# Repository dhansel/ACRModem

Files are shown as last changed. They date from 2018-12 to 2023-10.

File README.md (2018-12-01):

# ACRModem

The 88-ACR Audio Cassette Interface provided a means for Altair 8800 users
to save and load data on audio cassettes.

The 88-ACR consisted of two parts: A serial interface (identical to 88-SIO)
and a modulator/demodulator to convert the serial bit stream to an audio
signal (and vice versa).

This project represents the modulator/demodulator part, to be used with the
[Altair 8800 Simulator](https://www.hackster.io/david-hansel/arduino-altair-8800-simulator-3594a6). The function is fairly simple:
1) Connect the serial input of the modulator/demodulator board
to a serial interface of the Altair Simulator.
2) Connect the audio input of the board to the headphone output of an audio 
cassette recorder and the audio output of the board to the microphone
input of the cassette recorder.
3) Configure the serial interface on the Simulator for 300 baud.
4) In the Simulator configuration menu, map the 88-ACR card to the
serial interface to which the modulator/demodulator is connected.

Any data sent to the 88-ACR card by software running in the Simulator
should now appear on the microphone input of the cassette recorder and
data played back on the recorder should be visible on the 88-ACR card.

You will likely need to adjust recording level and volume on the cassette
recorder to find levels that work well.

## Hardware

The modulator/demodulator hardware is based on an ATMega 328p MCU
and a LM358 OpAmp. The ACRModem.fzz Fritzing file contains the schematic
as well as a working stripboard layout.

## Software

The ACRModem.ino file can be uploaded to the ATMega using the Arduino
development GUI. There are plenty of descriptions on how to upload
Arduino sketches to a stand-alone ATMega available on the internet.
Search for "Breadboard Arduino" or use [this link](http://www.buildcircuit.com/make-arduino-on-breadboard-using-ftdi-breakout-board).

## Acknowledgements

This project is loosely based on Mike Douglas' implementation
of an [Audio Cassette Interface](http://altairclone.com/cassette.htm) 
for the [Altair 8800 clone](http://altairclone.com/).

Thanks to Mike for tracking down the original 88-ACR documentation,
collecting supporting files and making the plans for his interface [available to the public](http://altairclone.com/downloads/cassette_interface/Hardware).

Although the implementation is different, the function of the two should
be almost identical. Instead of building this project here, purchasing
one of Mike's interfaces and hooking it up to the Altair Simulator
should work just the same.

For much more information on how to use the cassette interface on the
Altair 8800, see Mike's [documentation](http://altairclone.com/downloads/manuals/Cassette%20Interface%20Manual.pdf) 
for his cassette interface. Obviously his documentation was written for the Altair Clone
so following the instructions will be slightly different when used with an Altair Simulator.

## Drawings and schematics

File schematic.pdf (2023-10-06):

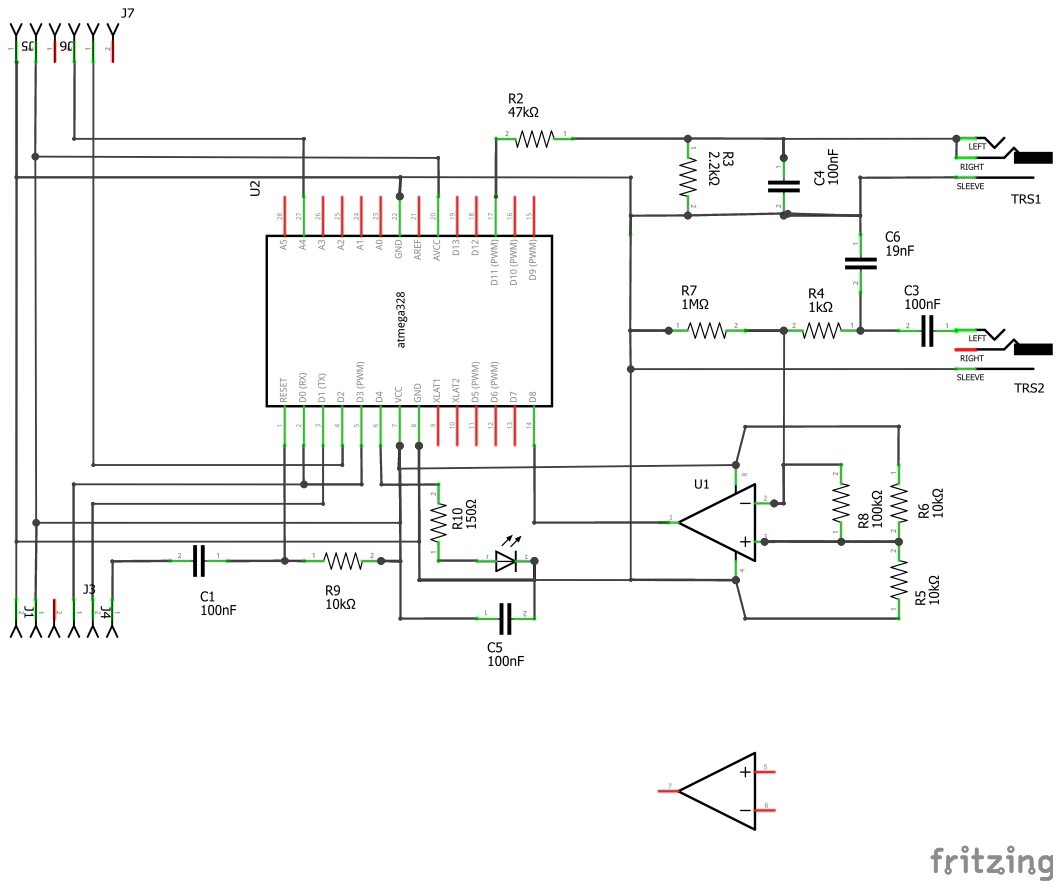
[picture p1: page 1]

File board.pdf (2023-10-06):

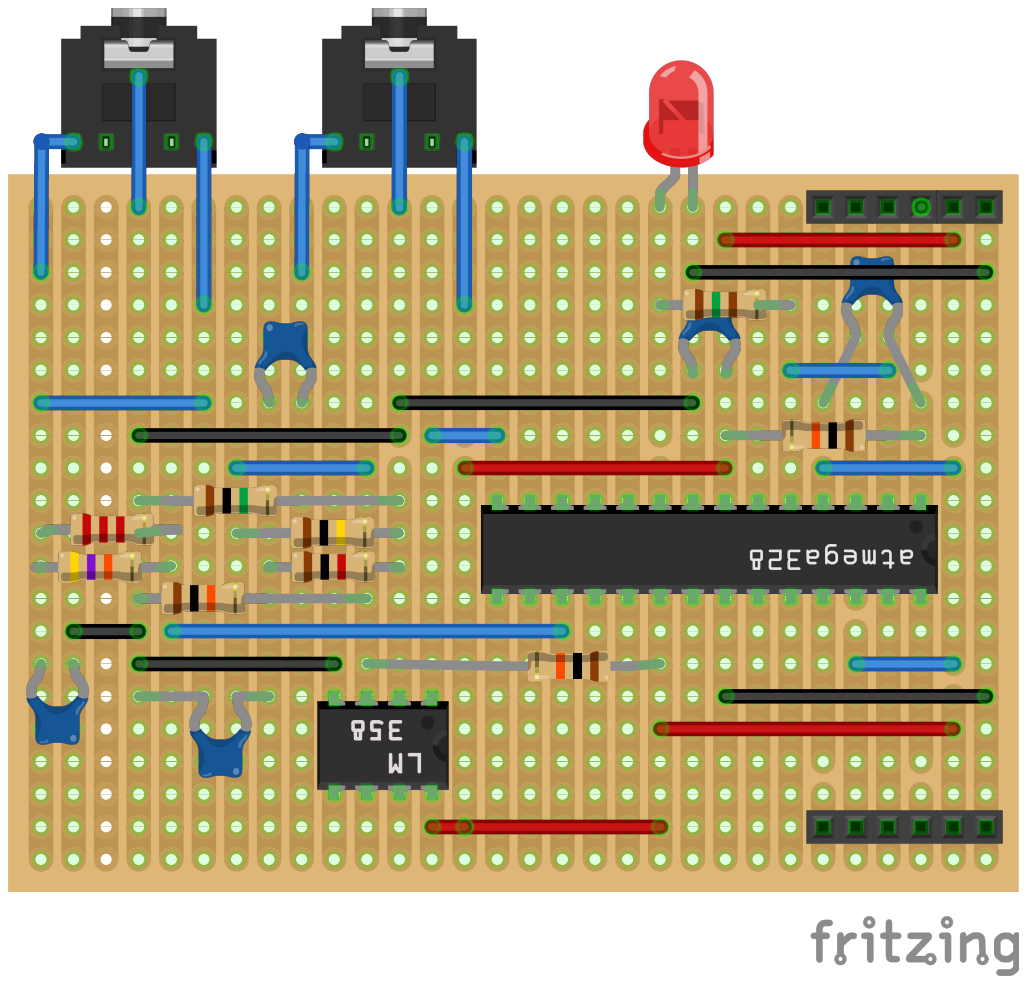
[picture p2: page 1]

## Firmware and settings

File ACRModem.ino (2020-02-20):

// -----------------------------------------------------------------------------
// Modulator/Demodulator for 88-ACR Altair Audio Cassette Interface (300 baud)
// Copyright (C) 2018 David Hansel
//
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
#define PIN_SERIAL_IN   2  // must be 2 or 3 (uses interrupt pin INT0 or INT1)
#define PIN_SERIAL_OUT A4  // can be any pin
#define PIN_AUDIO_IN    8  // must be  8 (hardwired ICP1 for timer1)
#define PIN_AUDIO_OUT  11  // must be 11 (hardwired OC2A for timer2)
#define PIN_LED         4  // can be any pin

// timing values for audio output:
// 8Mz main clock with /32 pre-scaler, the output toggles on 
// timer compare match so the timer must count up twice for a full wave:
#define OCRA_1850HZ  67 // 8000000/32/2/1850 = 67.57 = 541 microseconds
#define OCRA_2400HZ  52 // 8000000/32/2/2400 = 52.08 = 417 microseconds

// timing values for audio input
#define PERIOD_MAX_US 2000  // 1000Hz = 2000 microseconds
#define PERIOD_MID_US  471  // 2125Hz =  471 microseconds
#define PERIOD_MIN_US  333  // 3000Hz =  333 microseconds

// number of good audio pulses in a row required before entering "send" mode
#define NUM_GOOD_PULSES 100

// number of bad audio pulses in a row required before exiting "send" mode
// at 300 baud and audio frequencies of 1850 and 2400Hz, one bit is made up
// of 6-8 pulses. So if we just keep outputting the previous bit value then
// one or two bad pulses may not result in a receive error.
#define NUM_BAD_PULSES  3

// are we in "send" mode?
volatile bool send_data = false;

// timer value for current audio output frequency
volatile byte audio_out_timer_value = OCRA_2400HZ;


void got_pulse(bool good)
{
 static volatile byte good_pulses = 0, bad_pulses = 0;

 if( good )
  {
    bad_pulses = 0;
    if( good_pulses<NUM_GOOD_PULSES ) 
      {
        good_pulses++;
        if( good_pulses==NUM_GOOD_PULSES ) 
          { 
            digitalWrite(PIN_LED, HIGH); 
            send_data = true; 
          }
        else
          {
            // enable timer 1 overflow interrupt (checks for too-long pulse)
            TIFR1  |= bit(OCF1A);
            TIMSK1 |= bit(OCIE1A);
          }
      }
  }
 else if( bad_pulses<NUM_BAD_PULSES )
   {
     bad_pulses++;
     if( bad_pulses==NUM_BAD_PULSES )
       {
         good_pulses = 0;    
         if( send_data )
           {
             digitalWrite(PIN_LED, LOW); 
             digitalWrite(PIN_SERIAL_OUT, HIGH);
             send_data = false;
           }

         // disable timer 1 overflow interrupt (only needed while decoding)
         TIMSK1 &= ~bit(OCIE1A);
       }
   }
}


// called when timer 2 reaches its maximum value (compare match) 
// this interrupt only gets enabled when needed
ISR(TIMER2_COMPA_vect)
{
  // set audio out frequency for next wave
  OCR2A = audio_out_timer_value;  

  // disable interrupts for audio output timer (i.e. this ISR)
  TIMSK2 = 0;
}


// called when an edge is detected on the serial input
void serial_in_change()
{
  // reset compare match interrupt flag so we react to interrupts that
  // happen while (but not before) processing the serial input change
  TIFR2 = bit(OCIE2A);

  // read new serial input value
  bool data = digitalRead(PIN_SERIAL_IN);

  // set audio out frequency (wave length) depending on serial input
  audio_out_timer_value = data ? OCRA_2400HZ : OCRA_1850HZ;

  // forward data to pin 1 (external serial out)
  PORTD = (PORTD & ~0x02) | (data ? 0x02 : 0);

  // if the timer counter is smaller than target value (minus a small safety margin)
  // then set the new new target value now, otherwise enable compare match
  // interrupt and set the new target value in the interrupt handler
  if( TCNT2 < audio_out_timer_value-1 ) 
    OCR2A = audio_out_timer_value;
  else 
    TIMSK2 = bit(OCIE2A);
}


// called when an edge is detected on the external serial input
void extern_serial_in_change()
{
  // if not currently converting audio to serial then 
  // forward pin 1 (external serial in) to serial out
  if( !send_data ) digitalWrite(PIN_SERIAL_OUT, PIND & 0x01);
}


// called when a rising edge is detected at the ICP1 input (pin 8) 
ISR(TIMER1_CAPT_vect) 
{ 
  // reset timer 
  TCNT1 = 0;

  // reset output compare A interrupt in case it occurred simultaneously
  TIFR1 = bit(OCF1A);

  // timer ticks equals microseconds since previous rising edge
  // (8Mz clock with prescaler 8 => 1 microsecond per tick)
  unsigned int ticks = ICR1;

  if( ticks<PERIOD_MIN_US )
    got_pulse(false); // too short pulse => bad pulse
  else 
    {
      // detected pulse with PERIOD_MIN_US <= ticks <= PERIOD_MAX_US
      // (we can't get here with ticks>PERIOD_MAX_US
      // because the COMPA interrupt would have been triggered before that)
      static bool p1 = true, p2 = true;
      bool p3 = ticks<PERIOD_MID_US;
      
      if( p1!=p2 && p2!=p3 )
        {
          // of the three most recent pulses, the middle one was different
          // from the first and last => bad pulse (one bit is made up of 
          // about six pulses so there should never be a short->long->short
          // or long->short->long sequence)
          got_pulse(false);
          p2 = p3;
        }
      else
        {
          // previous pulse was good => send it.
          // note that what is being sent out the serial interface is two
          // pulses (or about 1/3 bit) behind the incoming audio: first the
          // incoming audio pulse has to complete before the computer can see
          // its length and then we stay one more pulse behind so we can
          // detect single-pulse errors (see above).
          got_pulse(true);
          if( send_data ) digitalWrite(PIN_SERIAL_OUT, p2);
          p1 = p2; p2 = p3;
        }
    }
}


// called when timer1 reaches its maximum value at PERIOD_MAX_US (2000)
ISR(TIMER1_COMPA_vect)
{  
  // reset timer 
  TCNT1 = 0;

  // reset input capture interrupt in case it occurred simultaneously
  TIFR1 = bit(ICF1);
  ICR1  = 0;
  
  // we haven't seen a rising edge for PERIOD_MAX_US microseconds => bad pulse
  got_pulse(false);
}


void setup() 
{
  // calibration for internal oscillator (not necessary if using crystal)
  // change value such that output square wave on pin 11 is close to 
  // 2400Hz when NOT sending any serial data
  OSCCAL = 0x8e;

  // set up timer2 to produce 1850/2400Hz output wave on OC2A (pin 11)
  // WGM22:20 = 010 => clear-timer-on-compare (CTC) mode 
  // COM2A1:0 =  01 => toggle OC2A on compare match
  // CS22:20  = 011 => CLK/32 prescaler
  TCCR2A = bit(COM2A0) | bit(WGM21);
  TCCR2B = bit(CS21) | bit(CS20);

  // set initial audio output frequency
  audio_out_timer_value = OCRA_2400HZ;
  OCR2A  = audio_out_timer_value;

  // set up serial input to create an interrupt on signal change
  pinMode(PIN_SERIAL_IN, INPUT_PULLUP);
  attachInterrupt(digitalPinToInterrupt(PIN_SERIAL_IN), serial_in_change, CHANGE);

  // set up timer1 to create an input capture interrupt when detecting a 
  // rising edge at the ICP1 input (pin 8) or when reaching PERIOD_MAX_US
  TCCR1A = 0;  
  TCCR1B = bit(ICNC1) | bit(ICES1) | bit(CS11); // enable input capture noise canceler, select rising edge and prescaler 8
  TCCR1C = 0;  
  OCR1A  = PERIOD_MAX_US; // set up for output compare match A after PERIOD_MAX_US microseconds
  TIMSK1 = bit(ICF1); // enable interrupt on input capture

  // set up serial output
  pinMode(PIN_SERIAL_OUT, OUTPUT);
  digitalWrite(PIN_SERIAL_OUT, HIGH);

  // set up audio output
  pinMode(PIN_AUDIO_OUT, OUTPUT);

  // set up LED to signal whether we are receiving good data from audio
  pinMode(PIN_LED, OUTPUT);
  digitalWrite(PIN_LED, LOW);

  // set up pin 0/1 for forwarding between main and external serial
  // pin 0 must be connected to pin 3
  pinMode(0, INPUT_PULLUP);
  pinMode(1, OUTPUT);
  digitalWrite(1, HIGH);
  attachInterrupt(digitalPinToInterrupt(3), extern_serial_in_change, CHANGE);

  // disable timer0 overflow interrupt (DISABLES MILLIS() FUNCTION!)
  // necessary so we don't introduce timing errors when forwarding serial data
  // due to timer1 interrupt handling in Arduino core
  TIMSK0 &= ~bit(TOIE0);
}


void loop() 
{/* nothing to do here */}

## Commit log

2018-12-01 Initial checkin
    [ACRModem.fzz]
2018-12-20 Some improvements for better robustness against noise
    [ACRModem.fzz]
2020-02-20 Disable timer interrupts while idle (i.e. forwarding serial data) to avoid timing errors when forwarding serial data at higher baud rates.
    [ACRModem.ino]
2023-10-06 Added PDFs of schematic and board

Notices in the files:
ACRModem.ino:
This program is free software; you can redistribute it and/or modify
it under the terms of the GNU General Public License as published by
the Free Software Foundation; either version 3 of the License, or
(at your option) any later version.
